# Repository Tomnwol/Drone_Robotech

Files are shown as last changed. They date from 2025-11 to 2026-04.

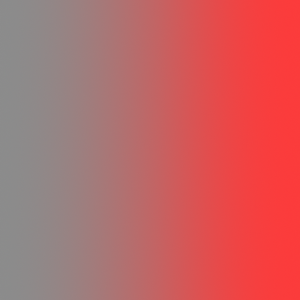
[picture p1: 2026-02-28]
Emitter/QT_Controller/half_texture.png

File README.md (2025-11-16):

Bienvenue dans le git du drone de **Robotech** 2025/2026.
Notre projet est de créer un drone 5" basé sur une ESP32.

# -- Démarche globale --

L'idée principale est d'utiliser un IMU 9 axes (accéléromètre, gyroscope, magnétomètre) pour obtenir une estimation d'attitude et ainsi pouvoir obtenir une commande angulaire qui sera par la suite exécutée par les moteurs.

# -- COMPOSANTS --

- Microprocesseur : *ESP32 DevKit*
- Accéléromètre/Gyroscope : *MPU-9265*
- Magnétomètre : *GY-271* (optionnel)
- Moteurs : *XING-E Pro 2207 1800KV 2-6S - Iflight*
- ESC : Hobbywing - *XRotor Micro 65A G2 4in1 AM32*
- Batterie : *LiPo GNB 6S 2200mAh 120C - XT60 - Gaoneng*
- Antenne RF : *NRF24L01 + PA/LNA*
- Frame : créée sur Fusion et imprimée en 3D
- PCB : créé sur Kicad 9

# -- CODE --

Pour le code, après avoir eu des problèmes de librairie en ESP-IDF sur **PlatformIo** pour le DSHOT, nous avons finalement migré vers **Arduino IDE** pour avoir une version plus récente de la librairie DSHOTRMT.

# -- SIMULATION --

Un fichier de simulation est disponible dans le répertoire /Simulation et permet de visualiser si le calcul d'attitude est cohérent et de visualiser 4 réponses moteurs, permettant ainsi de modifier les PID en conséquence.

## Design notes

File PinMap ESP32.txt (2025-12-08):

Association des GPIO de notre ESP-32 DevKit (30 pins)
GPIO 13 -> Moteur 1
GPIO 12 -> ReadyToFlyLED
GPIO 14 -> SDA1
GPIO 27 -> Moteur 2
GPIO 26 -> Moteur 3               
GPIO 25 -> SCL1
GPIO 33 -> Moteur 4
GPIO 32 
GPIO 35
GPIO 34 -> GPLED
GPIO 39
GPIO 36 -> Cut moteur si batterie trop faible
GPIO 15
GPIO 02
GPIO 04 -> CE_NRF
GPIO 16
GPIO 17
GPIO 05 -> CSN_NRF
GPIO 18 -> SCK
GPIO 19 -> MISO_NRF
GPIO 21 -> SDA0
GPIO 03
GPIO 01
GPIO 22 -> SCL0
GPIO 23 -> MOSI_NRF

Pinout moteur fonctionnel
13, 26, 27, 33

Défectueux : 14, 32

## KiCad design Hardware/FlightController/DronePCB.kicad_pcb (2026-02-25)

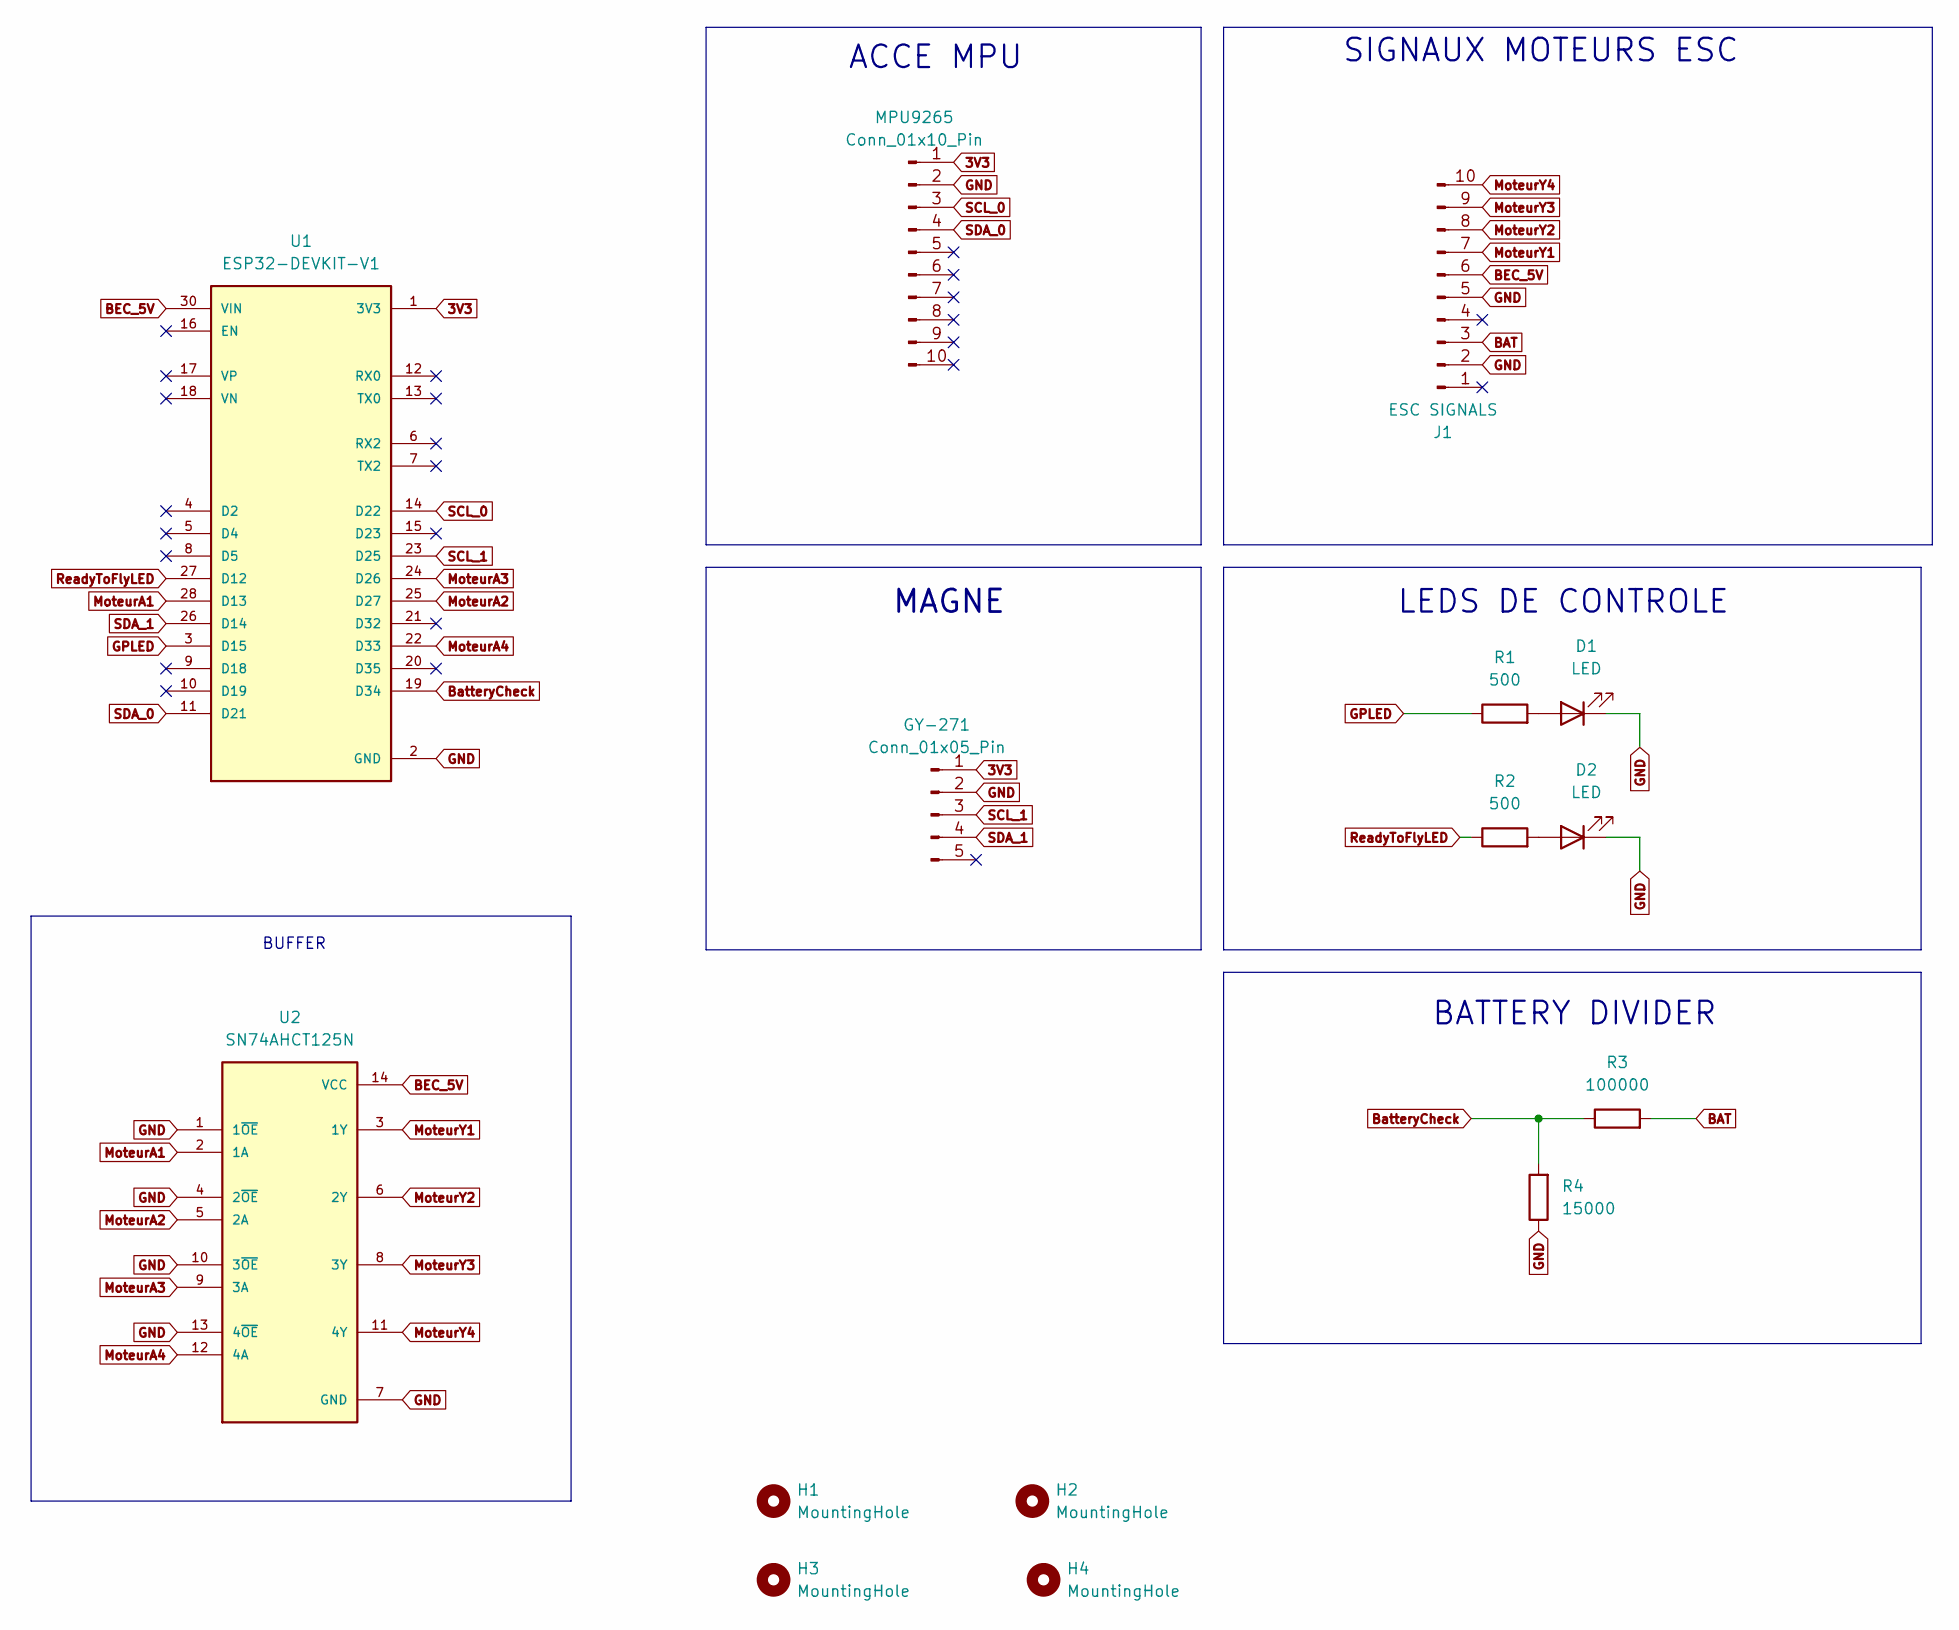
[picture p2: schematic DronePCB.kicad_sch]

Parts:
D1, D2: LED; LED_0603_1608Metric_Pad1.05x0.95mm_HandSolder
GY-271: Conn_01x05_Pin; PinHeader_1x05_P2.54mm_Vertical
H1, H2, H3, H4: MountingHole; MountingHole_3.2mm_M3_Pad
J1: ESC SIGNALS; JST_SHL_SM10B-SHLS-TF_1x10-1MP_P1.00mm_Horizontal
MPU9265: Conn_01x10_Pin; PinHeader_1x10_P2.54mm_Vertical
R1, R2: 500; R_0603_1608Metric_Pad0.98x0.95mm_HandSolder
R3: 100000; R_0603_1608Metric_Pad0.98x0.95mm_HandSolder
R4: 15000; R_0603_1608Metric_Pad0.98x0.95mm_HandSolder
U1: ESP32-DEVKIT-V1; MODULE_ESP32_DEVKIT_V1; PARTREV N/A
U2: SN74AHCT125N; DIP794W45P254L1930H508Q14; PARTREV Q

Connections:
3V3: GY-271.1, MPU9265.1, U1.1 (3V3)
BAT: J1.3, R3.2
BEC_5V: J1.6, U1.30 (VIN), U2.14 (VCC)
BatteryCheck: R3.1, R4.2, U1.19 (D34)
GND: D1.1 (K), D2.1 (K), GY-271.2, J1.2, J1.5, MPU9265.2, R4.1, U1.2 (GND), U1.29 (GND), U2.1 (1~OE), U2.4 (2~OE), U2.7 (GND), U2.10 (3~OE), U2.13 (4~OE)
GPLED: R1.1, U1.3 (D15)
MoteurA1: U1.28 (D13), U2.2 (1A)
MoteurA2: U1.25 (D27), U2.5 (2A)
MoteurA3: U1.24 (D26), U2.9 (3A)
MoteurA4: U1.22 (D33), U2.12 (4A)
MoteurY1: J1.7, U2.3 (1Y)
MoteurY2: J1.8, U2.6 (2Y)
MoteurY3: J1.9, U2.8 (3Y)
MoteurY4: J1.10, U2.11 (4Y)
unnamed: D1.2 (A), R1.2
unnamed: D2.2 (A), R2.2
ReadyToFlyLED: R2.1, U1.27 (D12)
SCL_0: MPU9265.3, U1.14 (D22)
SCL_1: GY-271.3, U1.23 (D25)
SDA_0: MPU9265.4, U1.11 (D21)
SDA_1: GY-271.4, U1.26 (D14)

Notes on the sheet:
ACCE MPU
MAGNE
BUFFER
BATTERY DIVIDER
LEDS DE CONTROLE
SIGNAUX MOTEURS ESC

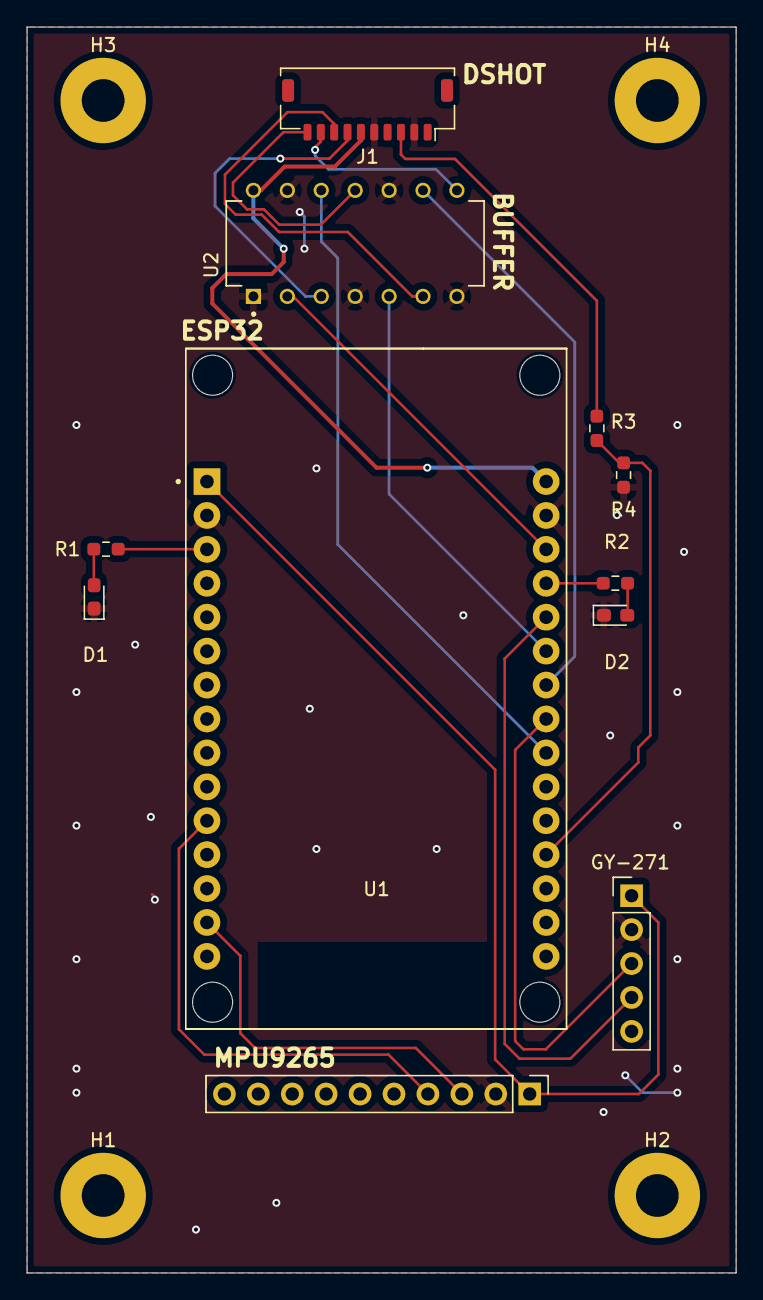
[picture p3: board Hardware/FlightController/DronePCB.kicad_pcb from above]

Board: 2 copper layers, 53.1 x 93.3 mm, 15 parts (0 on the bottom side), 21 nets.

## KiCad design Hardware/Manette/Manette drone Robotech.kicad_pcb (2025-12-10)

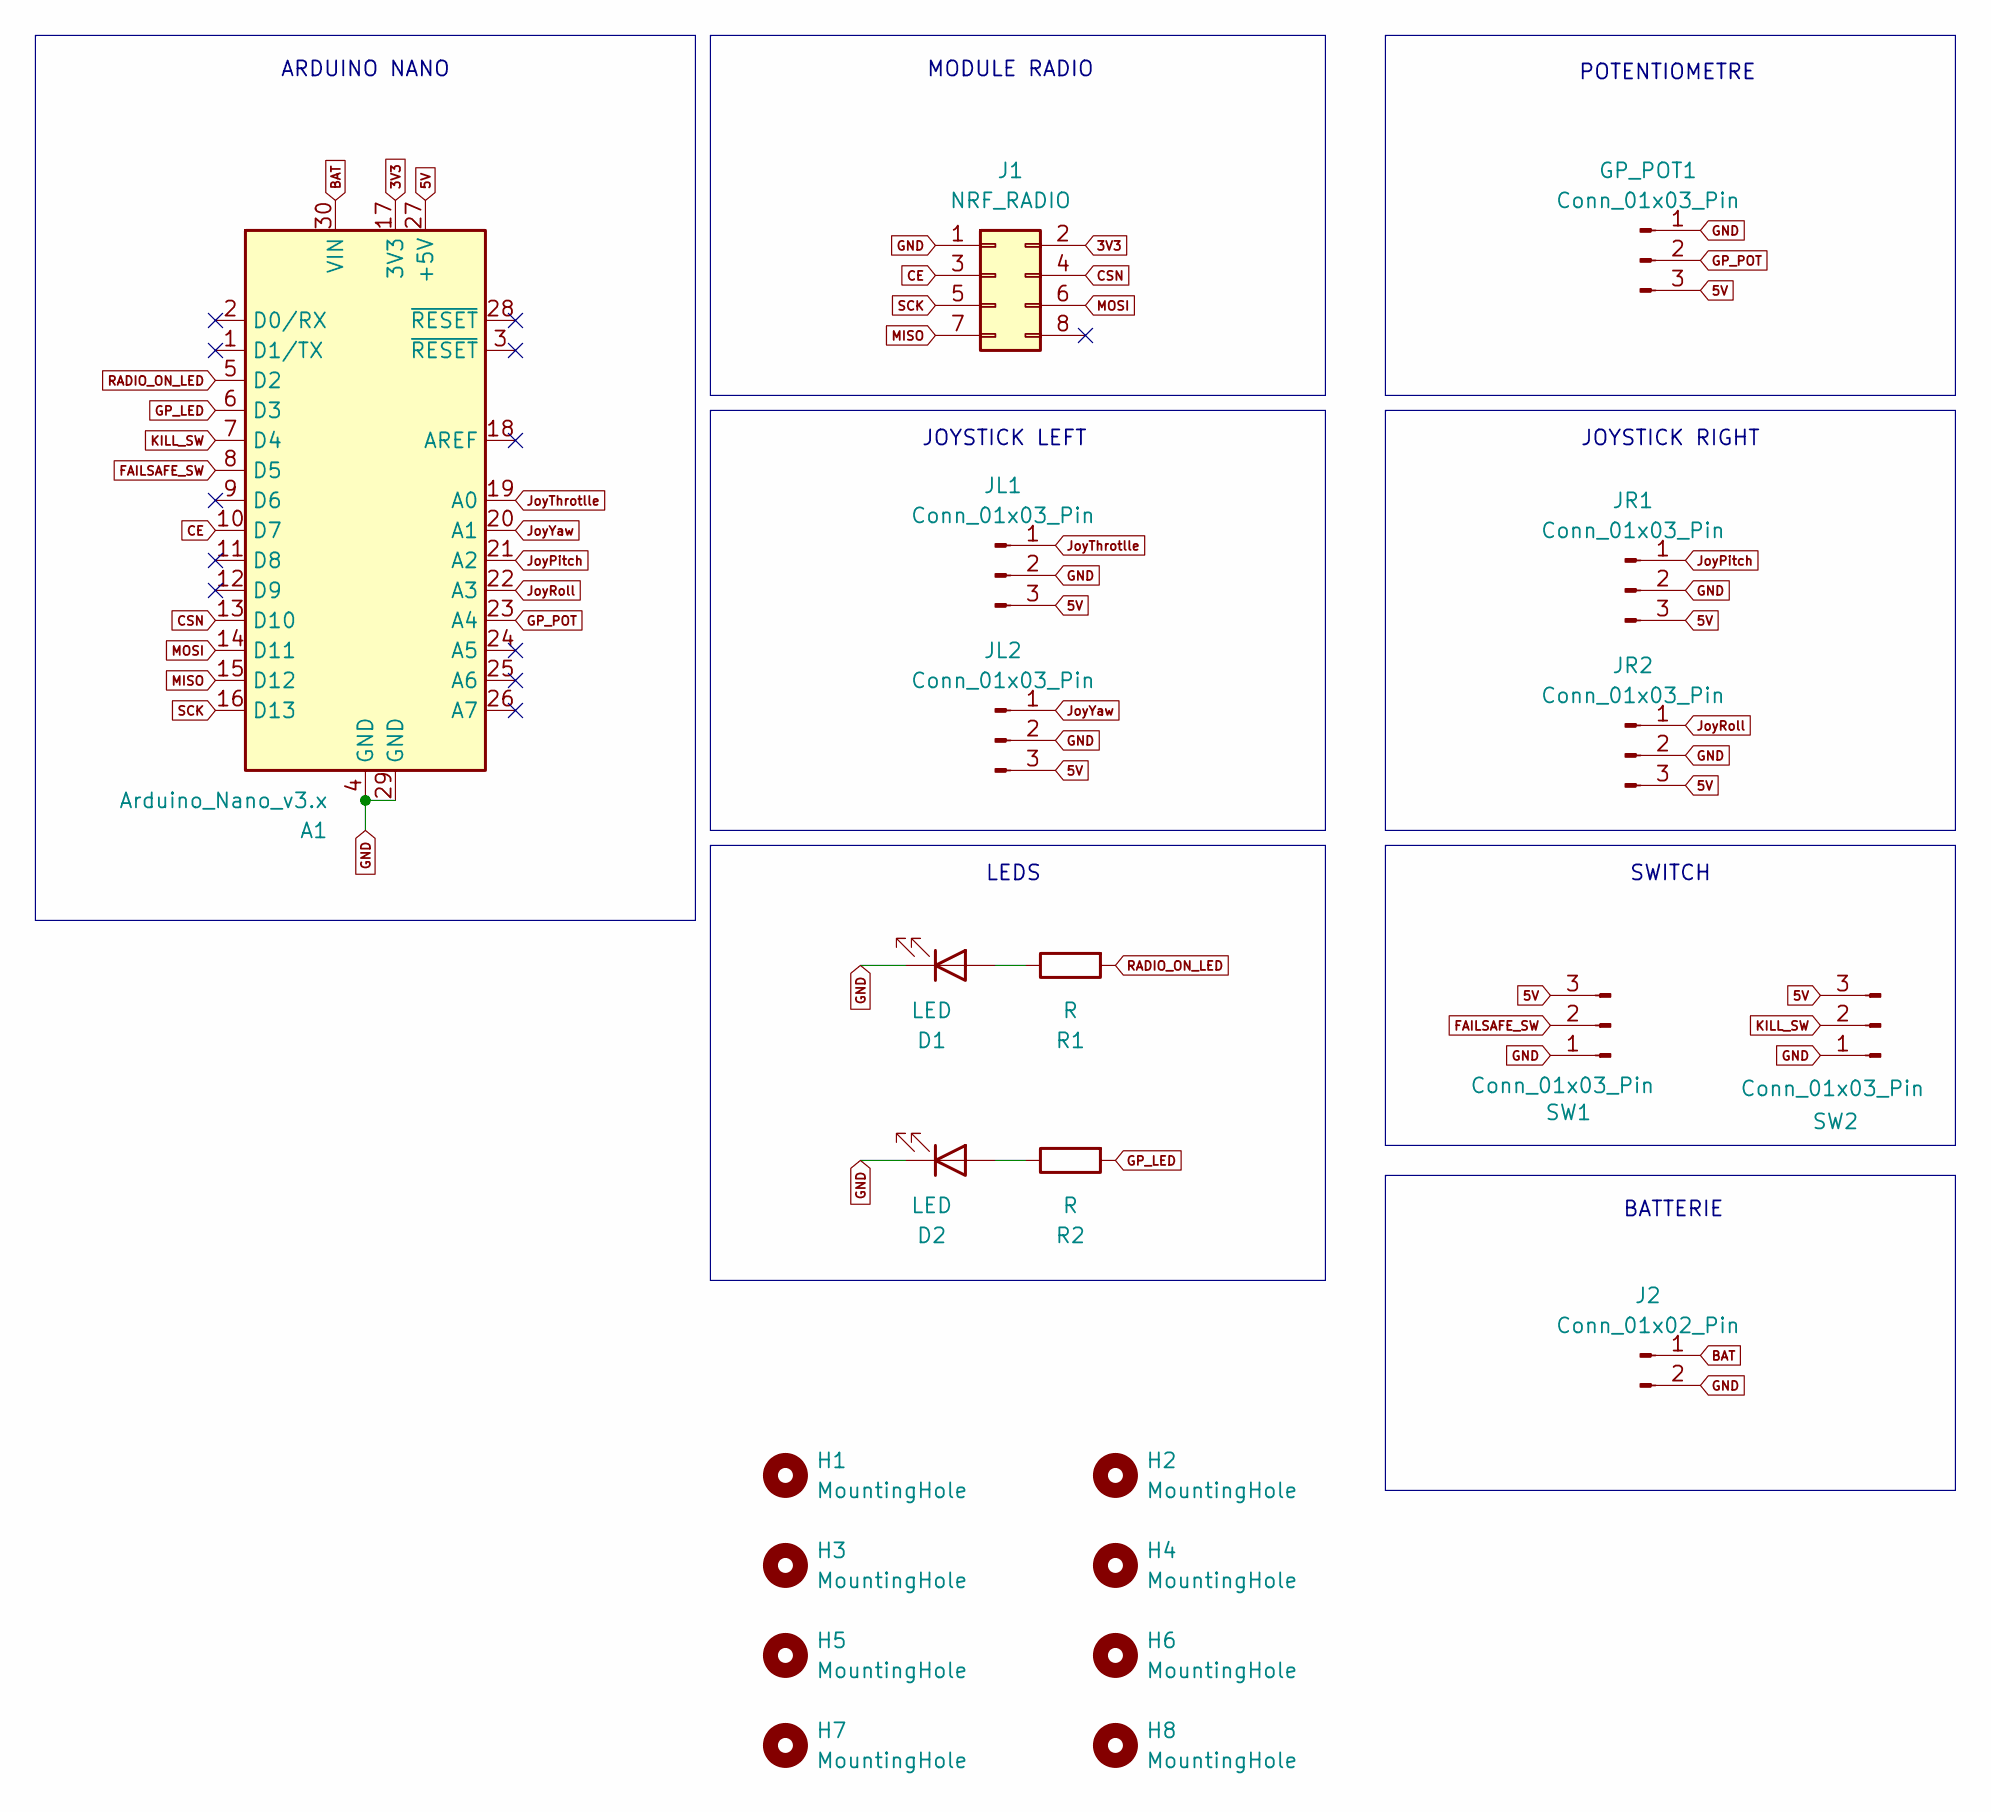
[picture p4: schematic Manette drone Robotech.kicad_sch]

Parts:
A1: Arduino_Nano_v3.x; Arduino_Nano
D1, D2: LED; LED_0603_1608Metric_Pad1.05x0.95mm_HandSolder
GP_POT1: Conn_01x03_Pin; PinHeader_1x03_P2.54mm_Vertical
H1, H2, H3, H4, H5, H6, H7, H8: MountingHole; MountingHole_3.2mm_M3_Pad
J1: NRF_RADIO; PinHeader_2x04_P2.54mm_Vertical
J2: Conn_01x02_Pin; PinHeader_1x02_P2.54mm_Vertical
JL1, JL2: Conn_01x03_Pin; PinHeader_1x03_P2.54mm_Vertical
JR1, JR2: Conn_01x03_Pin; PinHeader_1x03_P2.54mm_Vertical
R1, R2: R; R_0603_1608Metric_Pad0.98x0.95mm_HandSolder
SW1, SW2: Conn_01x03_Pin; PinHeader_1x03_P2.54mm_Vertical

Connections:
3V3: A1.17 (3V3), J1.2
5V: A1.27 (+5V), GP_POT1.3, JL1.3, JL2.3, JR1.3, JR2.3, SW1.3, SW2.3
BAT: A1.30 (VIN), J2.1
CE: A1.10 (D7), J1.3
CSN: A1.13 (D10), J1.4
FAILSAFE_SW: A1.8 (D5), SW1.2
GND: A1.4 (GND), A1.29 (GND), D1.1 (K), D2.1 (K), GP_POT1.1, J1.1, J2.2, JL1.2, JL2.2, JR1.2, JR2.2, SW1.1, SW2.1
GP_LED: A1.6 (D3), R2.2
GP_POT: A1.23 (A4), GP_POT1.2
JoyPitch: A1.21 (A2), JR1.1
JoyRoll: A1.22 (A3), JR2.1
JoyThrotlle: A1.19 (A0), JL1.1
JoyYaw: A1.20 (A1), JL2.1
KILL_SW: A1.7 (D4), SW2.2
MISO: A1.15 (D12), J1.7
MOSI: A1.14 (D11), J1.6
unnamed: D1.2 (A), R1.1
unnamed: D2.2 (A), R2.1
RADIO_ON_LED: A1.5 (D2), R1.2
SCK: A1.16 (D13), J1.5

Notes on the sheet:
JOYSTICK LEFT
JOYSTICK RIGHT
MODULE RADIO
SWITCH
LEDS
BATTERIE
POTENTIOMETRE
ARDUINO NANO

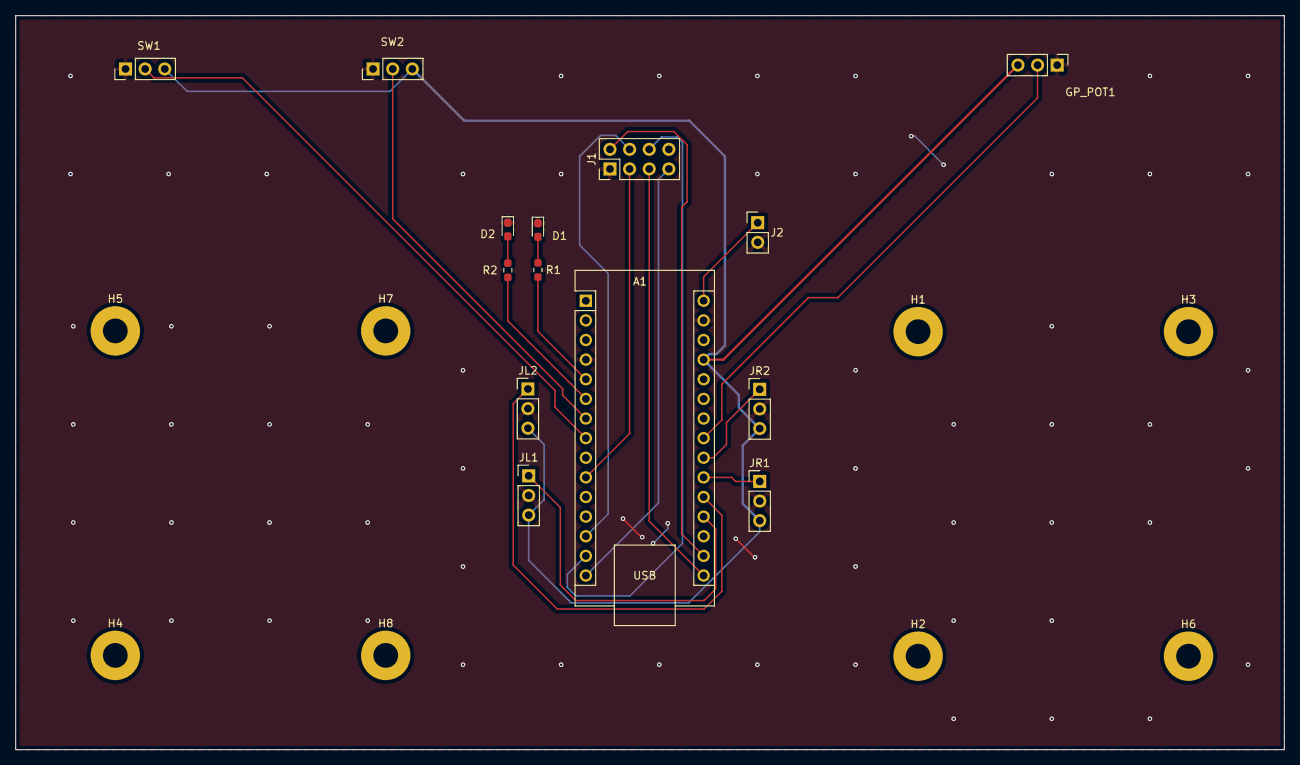
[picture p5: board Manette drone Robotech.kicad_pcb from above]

Board: 2 copper layers, 164.2 x 95.0 mm, 22 parts (0 on the bottom side), 20 nets.

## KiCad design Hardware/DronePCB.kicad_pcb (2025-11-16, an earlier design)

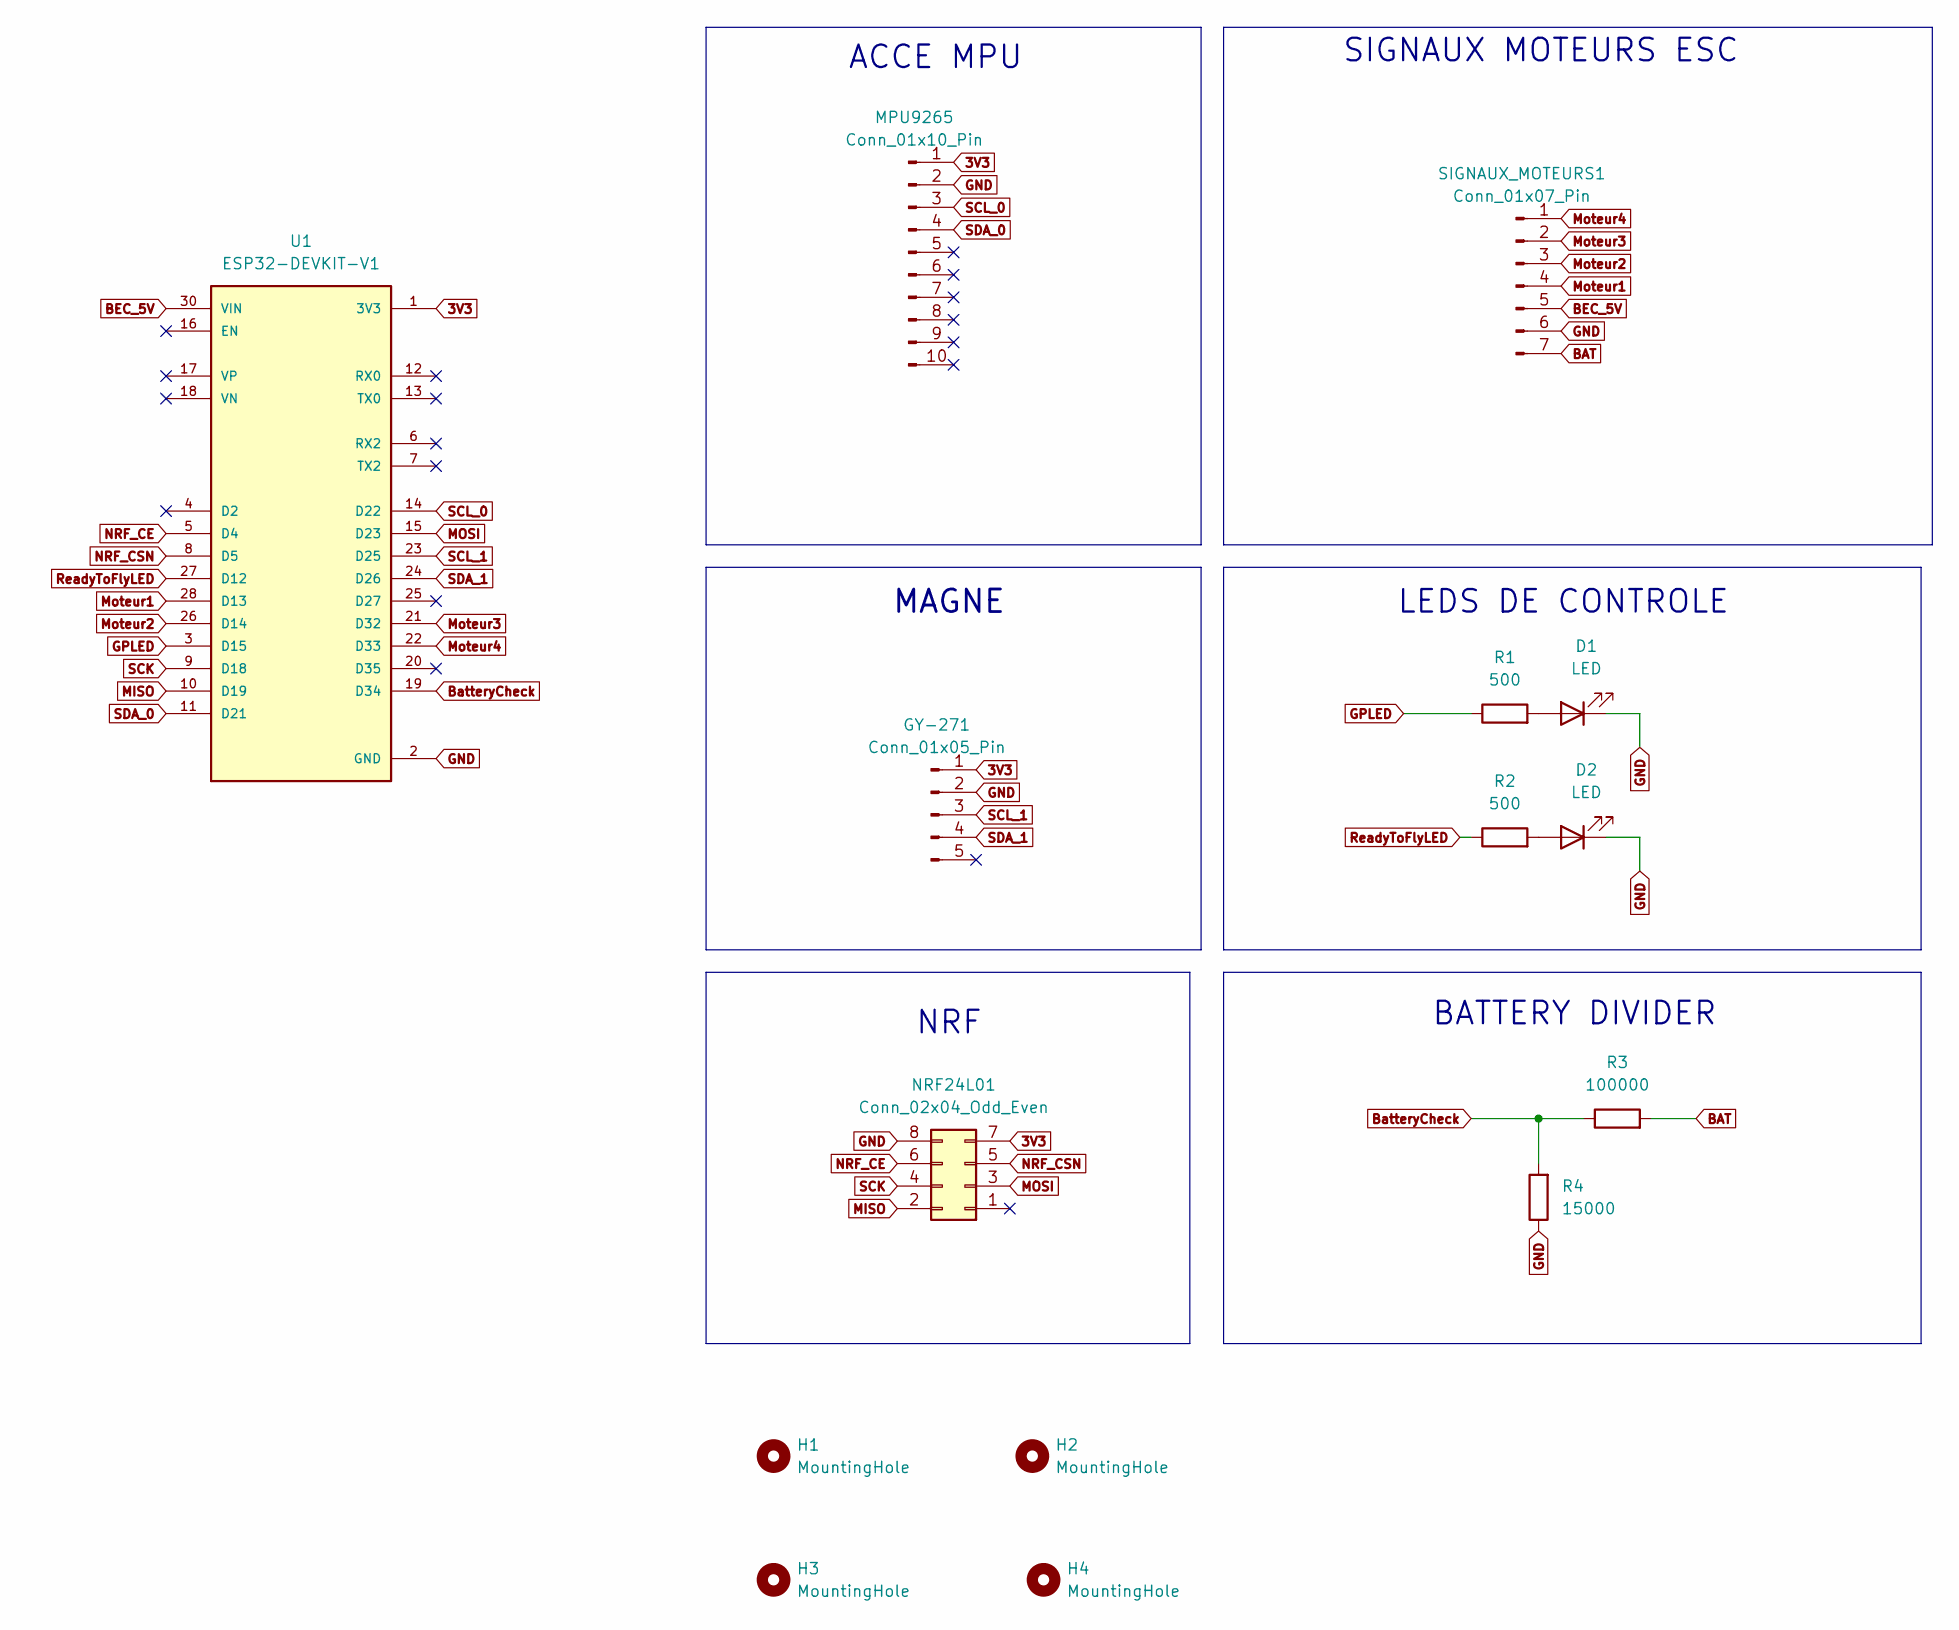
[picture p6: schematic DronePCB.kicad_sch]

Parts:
D1, D2: LED; LED_0603_1608Metric_Pad1.05x0.95mm_HandSolder
GY-271: Conn_01x05_Pin; PinHeader_1x05_P2.54mm_Vertical
H1, H2, H3, H4: MountingHole; MountingHole_3.2mm_M3_Pad
MPU9265: Conn_01x10_Pin; PinHeader_1x10_P2.54mm_Vertical
NRF24L01: Conn_02x04_Odd_Even; PinHeader_2x04_P2.00mm_Vertical
R1, R2: 500; R_0603_1608Metric_Pad0.98x0.95mm_HandSolder
R3: 100000; R_0603_1608Metric_Pad0.98x0.95mm_HandSolder
R4: 15000; R_0603_1608Metric_Pad0.98x0.95mm_HandSolder
SIGNAUX_MOTEURS1: Conn_01x07_Pin; PinHeader_1x07_P2.54mm_Vertical
U1: ESP32-DEVKIT-V1; MODULE_ESP32_DEVKIT_V1; PARTREV N/A

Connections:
3V3: GY-271.1, MPU9265.1, NRF24L01.7, U1.1 (3V3)
BAT: R3.2, SIGNAUX_MOTEURS1.7; also elsewhere on the board
BEC_5V: SIGNAUX_MOTEURS1.5, U1.30 (VIN); also elsewhere on the board
BatteryCheck: R3.1, R4.2, U1.19 (D34)
GND: D1.1 (K), D2.1 (K), GY-271.2, MPU9265.2, NRF24L01.8, R4.1, SIGNAUX_MOTEURS1.6, U1.2 (GND), U1.29 (GND); also elsewhere on the board
GPLED: R1.1, U1.3 (D15)
MISO: NRF24L01.2, U1.10 (D19)
MOSI: NRF24L01.3, U1.15 (D23)
Moteur1: SIGNAUX_MOTEURS1.4, U1.28 (D13); also elsewhere on the board
Moteur2: SIGNAUX_MOTEURS1.3, U1.26 (D14); also elsewhere on the board
Moteur3: SIGNAUX_MOTEURS1.2, U1.21 (D32); also elsewhere on the board
Moteur4: SIGNAUX_MOTEURS1.1, U1.22 (D33); also elsewhere on the board
NRF_CE: NRF24L01.6, U1.5 (D4)
NRF_CSN: NRF24L01.5, U1.8 (D5)
unnamed: D1.2 (A), R1.2
unnamed: D2.2 (A), R2.2
ReadyToFlyLED: R2.1, U1.27 (D12)
SCK: NRF24L01.4, U1.9 (D18)
SCL_0: MPU9265.3, U1.14 (D22)
SCL_1: GY-271.3, U1.23 (D25)
SDA_0: MPU9265.4, U1.11 (D21)
SDA_1: GY-271.4, U1.24 (D26)

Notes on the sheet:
ACCE MPU
MAGNE
BATTERY DIVIDER
LEDS DE CONTROLE
SIGNAUX MOTEURS ESC
NRF

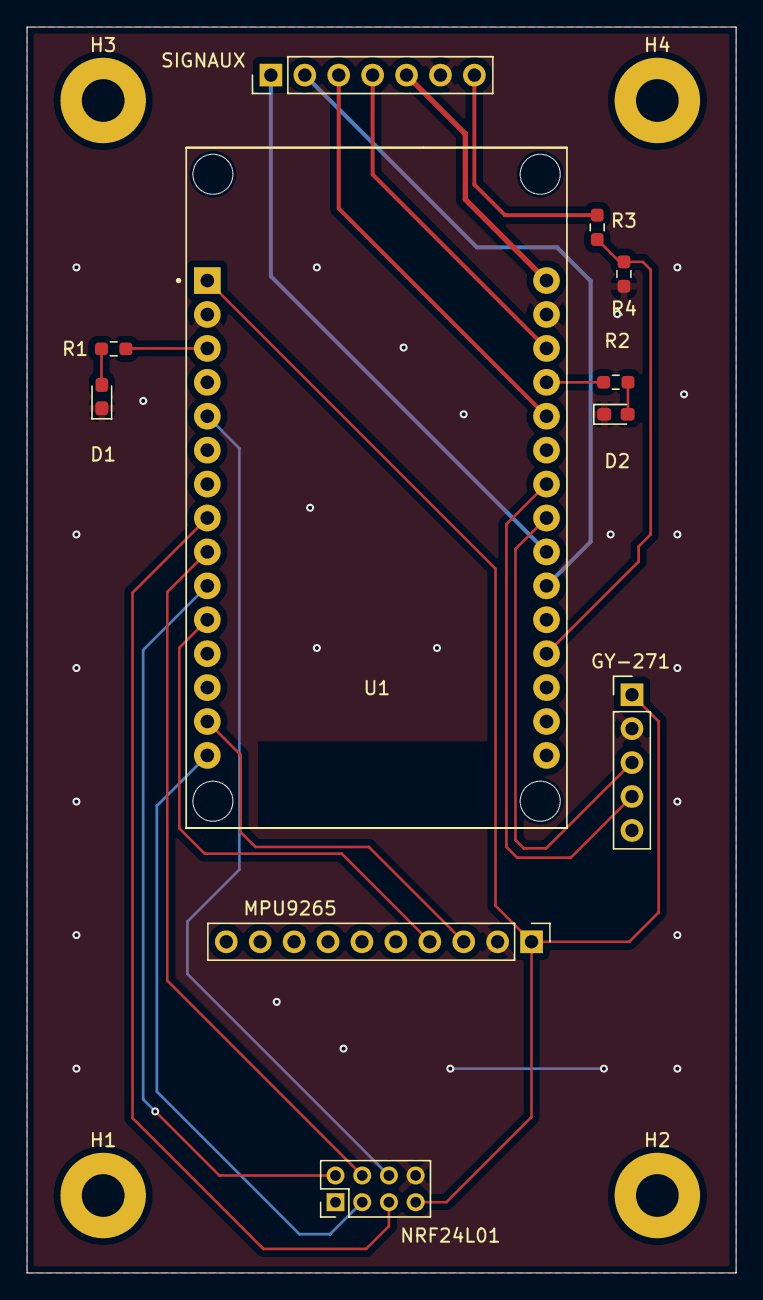
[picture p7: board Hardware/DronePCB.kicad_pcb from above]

Board: 2 copper layers, 53.1 x 93.3 mm, 15 parts (0 on the bottom side), 22 nets.

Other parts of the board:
SIGNAUX: Conn_01x07_Pin; PinHeader_1x07_P2.54mm_Vertical

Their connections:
BAT: SIGNAUX.7; also elsewhere on the board
BEC_5V: SIGNAUX.5; also elsewhere on the board
GND: SIGNAUX.6; also elsewhere on the board
Moteur1: SIGNAUX.4; also elsewhere on the board
Moteur2: SIGNAUX.3; also elsewhere on the board
Moteur3: SIGNAUX.2; also elsewhere on the board
Moteur4: SIGNAUX.1; also elsewhere on the board

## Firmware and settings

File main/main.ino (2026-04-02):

//#include "Arduino.h"
#include <stdio.h>
#include <Arduino.h>
#include <DShotRMT.h>
#include "i2c_basics.hpp"
#include "MadgwickAHRS.hpp"
#include "esp_timer.h"
#include "esp_log.h"
#include "imu.hpp"
#include "types.hpp"
#include "utils.hpp"
#include "UDP_reception.hpp"
//#include "NRF_receiver.hpp"
#include "pid.hpp"

static constexpr gpio_num_t MOTOR_FL_PIN = GPIO_NUM_13; //MOT1
static constexpr gpio_num_t MOTOR_FR_PIN = GPIO_NUM_26;//GPIO_NUM_32; //MOT3
static constexpr gpio_num_t MOTOR_BL_PIN = GPIO_NUM_27;//GPIO_NUM_14; //MOT2
static constexpr gpio_num_t MOTOR_BR_PIN = GPIO_NUM_33; //MOT4
static constexpr gpio_num_t ARM_LED = GPIO_NUM_12; //HIGH state indicates that the drone is ready to fly
static constexpr gpio_num_t GP_LED = GPIO_NUM_15;
static constexpr dshot_mode_t MODE = DSHOT600;
DShotRMT motorFL(MOTOR_FL_PIN, MODE, false);
DShotRMT motorFR(MOTOR_FR_PIN, MODE, false);
DShotRMT motorBL(MOTOR_BL_PIN, MODE, false);
DShotRMT motorBR(MOTOR_BR_PIN, MODE, false);

#define TIME_BEFORE_MOTOR_ACTIVATION 20000000
#define BASE_THRUST_MIN 100
#define BASE_THRUST_MAX 1900
#define BASE_THRUST_MAX_FAILSAFE 700
#define BASE_THRUST_FAILSAFE_AUTO 400

#define MOTOR_MAX_VALUE 2047
#define MOTOR_FAILSAFE_MAX_VALUE 800

#define MOTOR_SLEW_RATE 2000 //DSHOT units/s 
#define OFFSET_MOTOR_MAX 100
int failsafe_mode = 0; /* 0->OK  1->Activation FS par radio  2->Communication perdue */
bool killswitch_enable = false; /* Si le mode KS est activé, il ne pourra plus être désactivé avant redémarrage */ 
bool is_arm_mode_enable = false;
#define SIZE_TAB  2
float tab_acce[3][SIZE_TAB] = {{0},{0},{0}}; //stocke les dernières valeurs d'accélération
float tab_gyro[3][SIZE_TAB] = {{0},{0},{0}}; //stocke les dernières valeurs du gyro
float tab_magne[3][SIZE_TAB] = {{0},{0},{0}}; //stocke les dernières valeurs du mangétomètre

bool I2C_init_error = false;
void fill_queues(Vector3f accel_vect, Vector3f gyro_vect, Vector3f magne_vect){
    fill_queue(tab_acce[0], SIZE_TAB, accel_vect.x);
    fill_queue(tab_acce[1], SIZE_TAB, accel_vect.y);
    fill_queue(tab_acce[2], SIZE_TAB, accel_vect.z);
    fill_queue(tab_gyro[0], SIZE_TAB, gyro_vect.x);
    fill_queue(tab_gyro[1], SIZE_TAB, gyro_vect.y);
    fill_queue(tab_gyro[2], SIZE_TAB, gyro_vect.z);
    fill_queue(tab_magne[0], SIZE_TAB, magne_vect.x);
    fill_queue(tab_magne[1], SIZE_TAB, magne_vect.y);
    fill_queue(tab_magne[2], SIZE_TAB, magne_vect.z);
}

void passes_bas(float dt){
    float f_c_acce = 60.;
    float f_c_gyro = 130.;
    float f_c_magne = 50.;
    tab_acce[0][0] = passe_bas(tab_acce[0][0], tab_acce[0][1], dt, f_c_acce);
    tab_acce[1][0] = passe_bas(tab_acce[1][0], tab_acce[1][1], dt, f_c_acce);
    tab_acce[2][0] = passe_bas(tab_acce[2][0], tab_acce[2][1], dt, f_c_acce);

    tab_gyro[0][0] = passe_bas(tab_gyro[0][0], tab_gyro[0][1], dt, f_c_gyro);
    tab_gyro[1][0] = passe_bas(tab_gyro[1][0], tab_gyro[1][1], dt, f_c_gyro);
    tab_gyro[2][0] = passe_bas(tab_gyro[2][0], tab_gyro[2][1], dt, f_c_gyro);

    tab_magne[0][0] = passe_bas(tab_magne[0][0], tab_magne[0][1], dt, f_c_magne);
    tab_magne[1][0] = passe_bas(tab_magne[1][0], tab_magne[1][1], dt, f_c_magne);
    tab_magne[2][0] = passe_bas(tab_magne[2][0], tab_magne[2][1], dt, f_c_magne);
}


float get_base_thrust_max(){
    if (failsafe_mode){
      return BASE_THRUST_MAX_FAILSAFE;
    }else{
      return BASE_THRUST_MAX;
    }
}

float get_motor_max_value(){
    if (failsafe_mode){
      return MOTOR_FAILSAFE_MAX_VALUE;
    }else{
      return MOTOR_MAX_VALUE;
    }
}

float prev_mFL = 48.0f;
float prev_mFR = 48.0f;
float prev_mBR = 48.0f;
float prev_mBL = 48.0f;
void motors_zeroes(){
  prev_mFL = 48.0f; prev_mFR = 48.0f; prev_mBR = 48.0f; prev_mBL = 48.0f;
  motorFL.sendThrottle(48);
  motorFR.sendThrottle(48);
  motorBL.sendThrottle(48);
  motorBR.sendThrottle(48);
}

void motor_initial_sequence(){
  unsigned long start = millis();
  while (millis() - start < 1000) {
    motorFL.sendThrottle(0);
    motorFR.sendThrottle(0);
    motorBL.sendThrottle(0);
    motorBR.sendThrottle(0);
    delay(2);
  }
  delay(500);
  for (uint16_t t = 48; t <= 200; ++t) {
    motorFL.sendThrottle(t);
    motorFR.sendThrottle(t);
    motorBL.sendThrottle(t);
    motorBR.sendThrottle(t);
    delay(5); // ramp lente
  }
  // Retour à zéro
  for (uint16_t t = 200; t >= 48; --t) {
    motorFL.sendThrottle(t);
    motorFR.sendThrottle(t);
    motorBL.sendThrottle(t);
    motorBR.sendThrottle(t);
    delay(5);
  }
}

bool arm_mode_enable(){
  static int arming_counter = 0;
  if (joyThrottle == 48 && udp_delta_time < 100){
    arming_counter++;
    if (arming_counter >= 10){
      return true;
    }
  }else{
    arming_counter = 0;
  }
  return false;
}

bool is_kill_mode_enable(){ /* Non réversible mode -> désactivation des moteurs */
  if (killswitch_enable == false){
    if (is_arm_mode_enable && (udp_delta_time > 1000)){ //1500 ! Pour les TESTS ON MET + MAIS ATTENTION A BIEN REMETTRE 1500 PLUS TARD
      killswitch_enable = true;
      Serial.println("KS -> Communication failed");
      return true;
    }
    if (SWKillSwitch){ // Si la radio a reçu un signal KillSwitch
      killswitch_enable = true;
      Serial.println("KS -> KS flag received");
      return true;
    }else{
      return false;
    }
    return false;
  }else{
    return true;
  }
}

void failsafe_mode_activation(){  /* 0->OK  1->Activation par radio  2->Communication perdue */
  if (is_arm_mode_enable && udp_delta_time > 500){ // La radio ne répond plus depuis 0.5s => failsafe mode => limiation moteur
    failsafe_mode = 2;
    return;
  }
  failsafe_mode = SWFailSafe;
}

void error_loop_blink(){
  while(1){
    delay(200);
    Serial.println("KS_Activated");
    digitalWrite(GP_LED, HIGH);
    delay(200);
    digitalWrite(GP_LED, LOW);
  }
}

void fc_task() { 
    static int debug_counter_inner = 0;
    static unsigned long lastTime_outter = 0;
    static unsigned long lastTime_inner = 0;
    static int debug_counter = 0;
    static int debug_counter2 = 0;
    debug_counter_inner++;
    debug_counter2++;

    static int magne_compteur = 0;
    static Quaternion q_drone = {1, 0, 0, 0};
    static Vector3f omega_set = {0};
    static Vector3f magne_vect = {0, 0, 0};
    static Euler att_telemetry = {0,0,0};
    static float yawCommand = 0;
    static uint16_t MOT_FL_telemetry = 48;
    static uint16_t MOT_FR_telemetry = 48;
    static uint16_t MOT_BR_telemetry = 48;
    static uint16_t MOT_BL_telemetry = 48;

    handleSendTelemetry(att_telemetry, MOT_FL_telemetry, MOT_FR_telemetry, MOT_BR_telemetry, MOT_BL_telemetry);

    unsigned long now = micros(); // microsecondes
    float dt_inner = (now - lastTime_inner) / 1000000.0f; // s [Si bug -> Vérifier que dt_inner ne vaut jamais 0]
    lastTime_inner = now;

    // Lecture capteurs
    Vector3f accel_vect = read_accel();
    Vector3f gyro_vect  = read_gyro();
    magne_compteur++;
    fill_queues(accel_vect, gyro_vect, magne_vect);
    passes_bas(dt_inner);

    float dt_outer = (now - lastTime_outter) / 1000000.0f; // s
    /* OUTER LOOP */
    if (dt_outer > 0.004f) { // ~250 Hz
        lastTime_outter = now;
        float sampleFreqLocal = 1.0f / dt_outer;
        readUDPData();

        MadgwickAHRSupdate(
            sampleFreqLocal,
            tab_gyro[0][0], tab_gyro[1][0], tab_gyro[2][0],
            tab_acce[0][0], tab_acce[1][0], tab_acce[2][0],
            //tab_magne[0][0], tab_magne[1][0], tab_magne[2][0]
            0, 0, 0
        );
        q_drone.w = q0; q_drone.x = q1; q_drone.y = q2; q_drone.z = q3;
      
        Euler att = quat_to_euler(q_drone); // Obtiens l'attitude en Euler
        att_telemetry = att;
        const float SECURITY_ANGLE_RAD = 45.0f * M_PI / 180.0f;
        if (now > TIME_BEFORE_MOTOR_ACTIVATION * 0.8 && (fabs(att.roll) > SECURITY_ANGLE_RAD || fabs(att.pitch) > SECURITY_ANGLE_RAD)){
          killswitch_enable = true;
          Serial.println("KS -> Security angle");
        }

        Euler att_desired = get_att_desired();
        yawCommand = att_desired.yaw;
        omega_set = get_angular_rate_command(att, att_desired);
    }

    Vector3f torque = get_torque(omega_set, (Vector3f){tab_gyro[0][0], tab_gyro[1][0], tab_gyro[2][0]}, (Vector3f){tab_gyro[0][1], tab_gyro[1][1], tab_gyro[2][1]}, dt_inner);
    
    if (killswitch_enable){
      error_loop_blink();
    }
    bool motor_zero = false;
    if(now < TIME_BEFORE_MOTOR_ACTIVATION * 0.9 ){
      motor_zero = true;
    }
    digitalWrite(GP_LED, HIGH);
    // Vérification de l'armement du drone. Une fois que le drone est armé, ce n'est plus vérfié
    if (debug_counter2 >= 100) {
      debug_counter2 = 0;
      Serial.printf("DEBUG2:%d, %d\n", joyThrottle, udp_delta_time);
    }
    if( !is_arm_mode_enable ){ 
      is_arm_mode_enable = arm_mode_enable();

      if (is_arm_mode_enable){ //La LED prévient que le drone a été armé
        digitalWrite(ARM_LED, HIGH);
        //Ce serait mieux d'armer les moteurs ici, cependant, => Problématique en communication unidirectionnelle si un moteur failli ( et si on laisse une séquence de démarrage tout ça, après on a le problème de l'algo de Madwick qui se perd)
      }
      motor_zero = true;
    }
    
    failsafe_mode_activation();
    float base_thrust_max = get_base_thrust_max();
    float base_thrust;
    if (failsafe_mode != 2){
      base_thrust = (float)joyThrottle;
    }else{ // FS 2 -> Communication perdue
      base_thrust = BASE_THRUST_FAILSAFE_AUTO;
    }

    base_thrust = float_clamp(base_thrust, BASE_THRUST_MIN, base_thrust_max);


    if(now < TIME_BEFORE_MOTOR_ACTIVATION || is_kill_mode_enable()){ // ATTENTION A BIEN REGLER LA VALEUR DE DELTA RADIO LORS DUN VRAI VOL
      motor_zero = true;
    }
    //float commandYaw = joyYaw;
    float motor_max_value = get_motor_max_value();
    // Remarque: sur ce montage, l'IMU est orientée de 90°
    // => gyro.x = roulis (roll), gyro.y = tangage (pitch)
    //On peut viser : torque.x, torque.y ∈ [-100, +100] & base_thrust ∈ [100 à 1900]
    float mFL_target = float_clamp((base_thrust + torque.y - torque.x + yawCommand + uint8_clamp(offsetMotorFL, 0, OFFSET_MOTOR_MAX) ), 48.0, motor_max_value);
    float mFR_target = float_clamp((base_thrust + torque.y + torque.x - yawCommand + uint8_clamp(offsetMotorFR, 0, OFFSET_MOTOR_MAX) ), 48.0, motor_max_value);
    float mBR_target = float_clamp((base_thrust - torque.y + torque.x + yawCommand + uint8_clamp(offsetMotorBR, 0, OFFSET_MOTOR_MAX) ), 48.0, motor_max_value);
    float mBL_target = float_clamp((base_thrust - torque.y - torque.x - yawCommand + uint8_clamp(offsetMotorBL, 0, OFFSET_MOTOR_MAX) ), 48.0, motor_max_value);

    // Appliquer slew limiter par moteur
    prev_mFL = slew_limit(mFL_target, prev_mFL, MOTOR_SLEW_RATE, dt_inner);
    prev_mFR = slew_limit(mFR_target, prev_mFR, MOTOR_SLEW_RATE, dt_inner);
    prev_mBR = slew_limit(mBR_target, prev_mBR, MOTOR_SLEW_RATE, dt_inner);
    prev_mBL = slew_limit(mBL_target, prev_mBL, MOTOR_SLEW_RATE, dt_inner);

    uint16_t MOT_FL = (uint16_t)float_clamp(prev_mFL, 48.0, motor_max_value);
    uint16_t MOT_FR = (uint16_t)float_clamp(prev_mFR, 48.0, motor_max_value);
    uint16_t MOT_BR = (uint16_t)float_clamp(prev_mBR, 48.0, motor_max_value);
    uint16_t MOT_BL = (uint16_t)float_clamp(prev_mBL, 48.0, motor_max_value);


    if(!motor_zero){
      MOT_FL_telemetry = MOT_FL;
      MOT_FR_telemetry = MOT_FR;
      MOT_BR_telemetry = MOT_BR;
      MOT_BL_telemetry = MOT_BL;
      motorFL.sendThrottle(MOT_FL);
      motorFR.sendThrottle(MOT_FR);
      motorBL.sendThrottle(MOT_BL);
      motorBR.sendThrottle(MOT_BR);
    }else{
      MOT_FL_telemetry = 48;
      MOT_FR_telemetry = 48;
      MOT_BR_telemetry = 48;
      MOT_BL_telemetry = 48;
      motors_zeroes();
    }

    debug_counter++;
    if (debug_counter >= 200) {
        debug_counter = 0;
        //Afficher également les commandes Moteur1,2,3,4////////////////////////////////////////////////////
        //Serial.printf("%f,%f,%f,%f,%d,%d,%d,%d\n", q_drone.w, q_drone.x, q_drone.y, q_drone.z,MOT_FL,MOT_FR,MOT_BL,MOT_BR );
        
    }
    delay(1);
}



void setup() {
    Serial.begin(115200);
    pinMode(ARM_LED, OUTPUT);
    pinMode(GP_LED, OUTPUT);
    pinMode(BATTERY_PIN, INPUT);
    digitalWrite(GP_LED, LOW);
    digitalWrite(ARM_LED, LOW);
    i2c_master_init(I2C_MASTER_0_PORT, I2C_MASTER_0_SDA_IO, I2C_MASTER_0_SCL_IO, I2C_MASTER_0_FREQ_HZ);
    setupUDP();
    calibrate_gyro();
    delay(100);
    motorFL.begin();
    motorFR.begin();
    motorBL.begin();
    motorBR.begin();
    motor_initial_sequence();
    delay(5); //JTAG Delay test
}


void loop() {
    fc_task();
}

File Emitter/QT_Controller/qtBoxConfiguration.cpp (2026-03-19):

#include <QVBoxLayout>
#include <QLabel>
#include <QSlider>
#include <QDoubleSpinBox>
#include <QPushButton>
#include <QTimer>
#include "UDP.hpp"
#include "controller.hpp"
#include "configuration.hpp"
#include "qtBoxConfiguration.hpp"
#include "qtStyles.hpp"

#define OFFSET_MOTOR_MAX 100

QDoubleSpinBox *kpSpin;
QDoubleSpinBox *kiSpin;
QDoubleSpinBox *kdSpin;

QGroupBox *configurationGroupBox = nullptr; // WARNING : ne pas intialiser en global sinon crash
QTimer *timerConfigurationUpdate = nullptr;
void initConfigurationBox(Config* config){
    configurationGroupBox = new QGroupBox("Configuration");
    configurationGroupBox->setStyleSheet(TITLE_LABEL_STYLE);

    /****3.Left offset****/
    QLabel *OM_FL_Label = new QLabel("");
    QSlider *OM_FL_Slider = new QSlider(Qt::Horizontal);
    //OM_FL_Slider->setInvertedAppearance(true);
    OM_FL_Slider->setRange(0, OFFSET_MOTOR_MAX);
    OM_FL_Slider->setValue(my_config.offsetMotorFL);
    payload.offsetMotorFL = 0;
    OM_FL_Label->setText("FrontLeft : " + QString::number(OM_FL_Slider->value()));

    QLabel *OM_BL_Label = new QLabel("");
    QSlider *OM_BL_Slider = new QSlider(Qt::Horizontal);
    OM_BL_Slider->setRange(0, OFFSET_MOTOR_MAX);
    OM_BL_Slider->setValue(my_config.offsetMotorBL);
    payload.offsetMotorBL = 0;
    OM_BL_Label->setText("BackLeft : " + QString::number(OM_BL_Slider->value()));

    /****3.Right offset****/
    QLabel *OM_FR_Label = new QLabel("");
    QSlider *OM_FR_Slider = new QSlider(Qt::Horizontal);
    OM_FR_Slider->setRange(0, OFFSET_MOTOR_MAX);
    OM_FR_Slider->setValue(my_config.offsetMotorFR);
    payload.offsetMotorFR = 0;
    OM_FR_Label->setText("FrontRight : " + QString::number(OM_FR_Slider->value()));

    QLabel *OM_BR_Label = new QLabel("");
    QSlider *OM_BR_Slider = new QSlider(Qt::Horizontal);
    OM_BR_Slider->setRange(0, OFFSET_MOTOR_MAX);
    OM_BR_Slider->setValue(my_config.offsetMotorBR);
    payload.offsetMotorBR = 0;
    OM_BR_Label->setText("BackRight : " + QString::number(OM_BR_Slider->value()));

    OM_FL_Slider->setStyleSheet(SLIDER_STYLE);
    OM_BL_Slider->setStyleSheet(SLIDER_STYLE);
    OM_FR_Slider->setStyleSheet(SLIDER_STYLE);
    OM_BR_Slider->setStyleSheet(SLIDER_STYLE);

    /***2.Configuration->PID SpinBox***/
    QGroupBox *PID_GroupBox = new QGroupBox("PID Values");
    QVBoxLayout *vbox_PID = new QVBoxLayout;
    QLabel *kpLabel = new QLabel("Kp:");
    kpSpin = new QDoubleSpinBox();
    kpSpin->setRange(1.0, 200.0);    // plage de valeurs
    kpSpin->setSingleStep(0.5);      // incrément à chaque flèche
    kpSpin->setValue(config->Kp);           // valeur par défaut
    kpSpin->setDecimals(2);          // nombre de décimales affichées
    payload.KP = config->Kp * PID_MULTIPLICATOR;

    QLabel *kiLabel = new QLabel("Ki:");
    kiSpin = new QDoubleSpinBox();
    kiSpin->setRange(0.0, 400.0);    // plage de valeurs
    kiSpin->setSingleStep(0.5);      // incrément à chaque flèche
    kiSpin->setValue(config->Ki);           // valeur par défaut
    kiSpin->setDecimals(2);          // nombre de décimales affichées
    payload.KI = config->Ki * PID_MULTIPLICATOR;

    QLabel *kdLabel = new QLabel("Kd:");
    kdSpin = new QDoubleSpinBox();
    kdSpin->setRange(0.0, 150.0);    // plage de valeurs
    kdSpin->setSingleStep(0.5);      // incrément à chaque flèche
    kdSpin->setValue(config->Kd);           // valeur par défaut
    kdSpin->setDecimals(2);          // nombre de décimales affichées

    payload.KD = config->Kd * PID_MULTIPLICATOR;

    vbox_PID->addWidget(kpLabel);
    vbox_PID->addWidget(kpSpin);
    vbox_PID->addWidget(kiLabel);
    vbox_PID->addWidget(kiSpin);
    vbox_PID->addWidget(kdLabel);
    vbox_PID->addWidget(kdSpin);
    PID_GroupBox->setLayout(vbox_PID);

    /***2.Offset Motors***/
    QGroupBox *offsetsMotorsGroupBox = new QGroupBox("Offsets Motors");
    QGroupBox *offsetsMotorsGroupBoxLeft = new QGroupBox("");
    QGroupBox *offsetsMotorsGroupBoxRight = new QGroupBox("");
    QVBoxLayout *offsetsMotorsVboxLeft = new QVBoxLayout;
    QVBoxLayout *offsetsMotorsVboxRight = new QVBoxLayout;
    QHBoxLayout *offsetsMotorsHbox = new QHBoxLayout;

    offsetsMotorsVboxLeft->addWidget(OM_FL_Label);
    offsetsMotorsVboxLeft->addWidget(OM_FL_Slider);
    offsetsMotorsVboxLeft->addWidget(OM_BL_Label);
    offsetsMotorsVboxLeft->addWidget(OM_BL_Slider);
    offsetsMotorsGroupBoxLeft->setLayout(offsetsMotorsVboxLeft);

    offsetsMotorsVboxRight->addWidget(OM_FR_Label);
    offsetsMotorsVboxRight->addWidget(OM_FR_Slider);
    offsetsMotorsVboxRight->addWidget(OM_BR_Label);
    offsetsMotorsVboxRight->addWidget(OM_BR_Slider);
    offsetsMotorsGroupBoxRight->setLayout(offsetsMotorsVboxRight);

    offsetsMotorsHbox->addWidget(offsetsMotorsGroupBoxLeft);
    offsetsMotorsHbox->addWidget(offsetsMotorsGroupBoxRight);

    offsetsMotorsGroupBox->setLayout(offsetsMotorsHbox);
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

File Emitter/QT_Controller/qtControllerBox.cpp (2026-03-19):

#include <QWidget>
#include <QGroupBox>
#include <QCheckBox>
#include <QVBoxLayout>
#include <QSlider>
#include <QLabel>
#include <QString>
#include <QHBoxLayout>
#include <QShortcut>
#include <QKeyEvent>
#include <QTimer>
#include "qtControllerBox.hpp"
#include "configuration.hpp"

#include "UDP.hpp"
#include "qtStyles.hpp"

#define DSHOT_MIN 48
#define DSHOT_MAX 2047
#define DSHOT_MAX_FAILSAFE 700
#define ANGLE_MAX 1000  // (yaw/pitch/roll)

Controller* local_controller;
QGroupBox *controllerGroupBox = nullptr;
QTimer *timerControllerUpdate = nullptr;
bool KS_enable = false;

bool lastButtonA = false;
bool lastButtonB = false;
bool lastButtonY = false;
bool lastButtonX = false;

void initControllerBox(QWidget* window, Controller* controller){
    local_controller = controller;
    /***2.Security Box***/
    QGroupBox *securityGroupBox = new QGroupBox("Security");
    QCheckBox *FS_Check = new QCheckBox("FailSafe Switch (KeyF, X or Y)");
    QCheckBox *killCheck = new QCheckBox("Kill Switch (KeySpaceBar, A or B)", securityGroupBox);
    killCheck->setStyleSheet(
        "QCheckBox::indicator:checked {"
        "background-color: #aa0000;"
        "border: 1px solid black;"
        "}"
    );
    FS_Check->setChecked(true);
    payload.failSafeSwitch = 1;
    QVBoxLayout *securityVbox = new QVBoxLayout;
    securityVbox->addWidget(FS_Check);
    securityVbox->addWidget(killCheck);
    securityVbox->addStretch(1);
    securityGroupBox->setLayout(securityVbox);

    /***2.Motors Sliders***/
    QGroupBox *motorsGroupBox = new QGroupBox("Motors");
    QVBoxLayout *motorsVbox = new QVBoxLayout;
    QLabel *throttleLabel = new QLabel("");
    QLabel *yawLabel = new QLabel("");
    QLabel *rollLabel = new QLabel("");
    QLabel *pitchLabel = new QLabel("");
    QSlider *throttleSlider = new QSlider(Qt::Horizontal);
    QSlider *yawSlider = new QSlider(Qt::Horizontal);
    QSlider *rollSlider = new QSlider(Qt::Horizontal);
    QSlider *pitchSlider = new QSlider(Qt::Horizontal);

    if (FS_Check->isChecked()){
        throttleSlider->setRange(DSHOT_MIN, DSHOT_MAX_FAILSAFE);
        throttleValue = clampDouble(throttleValue, DSHOT_MIN, DSHOT_MAX_FAILSAFE);
    }else{
        throttleSlider->setRange(DSHOT_MIN, DSHOT_MAX);
    }
    throttleSlider->setValue(DSHOT_MIN);
    throttleSlider->setStyleSheet(SLIDER_STYLE);
    yawSlider->setStyleSheet(SLIDER_STYLE);
    rollSlider->setStyleSheet(SLIDER_STYLE);
    pitchSlider->setStyleSheet(SLIDER_STYLE);
    yawSlider->setRange(-ANGLE_MAX, +ANGLE_MAX);
    yawSlider->setValue(0);
    rollSlider->setRange(-ANGLE_MAX, +ANGLE_MAX);
    rollSlider->setValue(0);
    pitchSlider->setRange(-ANGLE_MAX, +ANGLE_MAX);
    pitchSlider->setValue(0);

    payload.yaw = 0;
    payload.roll = 0;
    payload.pitch = 0;
    payload.throttle = DSHOT_MIN;
    throttleLabel->setText("Throttle : " + QString::number(throttleSlider->value()));
    yawLabel->setText("Yaw : " + QString::number(yawSlider->value()));
    rollLabel->setText("Roll : " + QString::number(rollSlider->value()));
    pitchLabel->setText("Pitch : " + QString::number(pitchSlider->value()));
    motorsVbox->addWidget(throttleLabel);
    motorsVbox->addWidget(throttleSlider);
    motorsVbox->addWidget(pitchLabel);
    motorsVbox->addWidget(pitchSlider);
    motorsVbox->addWidget(rollLabel);
    motorsVbox->addWidget(rollSlider);
    motorsVbox->addWidget(yawLabel);
    motorsVbox->addWidget(yawSlider);
    motorsGroupBox->setLayout(motorsVbox);
    throttleLabel->setStyleSheet(LABEL_CONTROL_STYLE);
    pitchLabel->setStyleSheet(LABEL_CONTROL_STYLE);
    rollLabel->setStyleSheet(LABEL_CONTROL_STYLE);
    yawLabel->setStyleSheet(LABEL_CONTROL_STYLE);

    /**1.Controller**/
    controllerGroupBox = new QGroupBox("Controller");
    controllerGroupBox->setStyleSheet(TITLE_LABEL_STYLE);
    controllerGroupBox->setEnabled(false); // Control non disponible tant que le serial n'est pas activé
    QVBoxLayout *controllerVbox = new QVBoxLayout;

    //motorsGroupBox->setStyleSheet(NORMAL_LABEL_STYLE);
    //securityGroupBox->setStyleSheet(NORMAL_LABEL_STYLE);
    controllerVbox->addWidget(motorsGroupBox);
    controllerVbox->addWidget(securityGroupBox);
    controllerGroupBox->setLayout(controllerVbox);


    QShortcut *FS_Shortcut = new QShortcut(QKeySequence(Qt::Key_F), window);
    QObject::connect(FS_Shortcut, &QShortcut::activated, FS_Check, [FS_Check, throttleSlider]() { //Active/Désactive la limitation moteur (côté drone)
        if (not FS_Check->isChecked()){
            throttleSlider->setRange(DSHOT_MIN, DSHOT_MAX_FAILSAFE);
            throttleValue = clampDouble(throttleValue, DSHOT_MIN, DSHOT_MAX_FAILSAFE);
        }else{
            throttleSlider->setRange(DSHOT_MIN, DSHOT_MAX);
        }
        QSignalBlocker blocker(FS_Check);
        FS_Check->setChecked(not FS_Check->isChecked());
        payload.failSafeSwitch = FS_Check->isChecked(); //Update value for UART

    });
    QObject::connect(FS_Check, &QCheckBox::toggled, FS_Check, [FS_Check, throttleSlider](bool checked) {
        // Cette lambda est appelée à chaque clic sur la checkbox
        if (checked){
            throttleSlider->setRange(DSHOT_MIN, DSHOT_MAX_FAILSAFE);
            throttleValue = clampDouble(throttleValue, DSHOT_MIN, DSHOT_MAX_FAILSAFE);
        }else{
            throttleSlider->setRange(DSHOT_MIN, DSHOT_MAX);
        }

        QSignalBlocker blocker(FS_Check);
        payload.failSafeSwitch = checked;
    });


    QShortcut *killShortcut = new QShortcut(QKeySequence(Qt::Key_Space), window);
    QObject::connect(killShortcut,
                     &QShortcut::activated,
                     killCheck,
                     [killCheck]() {
                         if (KS_enable){
                             QSignalBlocker blocker(killCheck);
                             killCheck->setChecked(true);
                             killCheck->setEnabled(false);
                             payload.killSwitch = 1;
                         }
                     });

    QObject::connect(killCheck, &QCheckBox::toggled, killCheck, [killCheck](bool checked){ // Désactive l'option KS une fois activée
        checked=checked; // no effect, avoid warning
        QSignalBlocker blocker(killCheck);
        killCheck->setEnabled(false);
        payload.killSwitch = 1;
        std::cout << "KILLSWITCHED" << std::endl;
    });

    QObject::connect(throttleSlider, &QSlider::valueChanged, [throttleLabel](int value){ //Update la valeur de Throttle
        throttleLabel->setText("Throttle : " + QString::number(value));
        payload.throttle = value;  //Update value for UART
    });

    QObject::connect(yawSlider, &QSlider::valueChanged, [yawLabel](int value){ //Update la valeur de Throttle
        yawLabel->setText("Yaw : " + QString::number(value));
        payload.yaw = value;  //Update value for UART
    });
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

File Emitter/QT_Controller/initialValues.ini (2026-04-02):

[OFFSET]
offsetMotorBL=12
offsetMotorBR=0
offsetMotorFL=26
offsetMotorFR=0

[PID]
Kd=3
Ki=50
Kp=80

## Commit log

2025-10-16 Hard iron magnetometer correction
    [imu.c]
2025-10-23 PWM motors simu v1
2025-11-09 Portage FrameWork ESP IDF to Arduino
2025-11-10 Ajout script arduino pour telecommande
2025-11-10 Correction via yaw roll pitch fonctionnel
    [main.cpp]
2025-11-16 Kicad drone PCB
    [DronePCB-B_Cu.gbl, DronePCB-B_Mask.gbs, DronePCB-B_Paste.gbp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]
2025-12-03 Added Kicad for drone Remote Controller
    [Manette drone Robotech.kicad_pcb, Manette drone Robotech.kicad_sch]
2025-12-04 PCB Drone et manette finis avec gerbers générés
    [DronePCB-B_Cu.gbl, DronePCB-B_Mask.gbs, DronePCB-B_Paste.gbp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]
2025-12-04 mise a jour de tous les fichiers git
    [Manette drone Robotech.kicad_pcb, Manette drone Robotech.kicad_sch]
2025-12-05 Fix conversion issue on payload
    [main.ino]
2025-12-05 pid file
2025-12-05 KillSwitch delta radio a 5000 pour tester les reactions moteurs
2025-12-06 Correction Drone pinout et génération gerber
    [DronePCB-B_Cu.gbl, DronePCB-B_Mask.gbs, DronePCB-B_Paste.gbp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]
2025-12-10 gerbers et code fonctionnel cut a 45°
    [DronePCB-B_Cu.gbl, DronePCB-B_Mask.gbs, DronePCB-B_Paste.gbp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]
2026-01-10 Code recoit infos manette, gere le throttle, et gestion du killswitch OK. Cependant, PB de GPIO qui se détruisent, probablement pic de courant ou tension
2026-02-07 PID Kd and motors offsets added
2026-02-09 PID security update with I begin value
2026-02-11 Communication by UDP to avoid NRF24L01 bugs
    [UDP.cpp, UDP.hpp, UDP_reception.cpp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]
2026-02-14 Sauvegarde des offsets moteurs QT Interface
2026-02-14 Changement pas du PID slider QT interface
2026-02-15 Ajout Drone Box for battery data
2026-02-16 QT Interface for battery
2026-02-16 fix battery pin
2026-02-25 PCB avec nouveau connecteur JST SH + buffer
    [DronePCB-B_Cu.gbl, DronePCB-B_Mask.gbs, DronePCB-B_Paste.gbp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]
2026-02-25 Critique : Inclusion de ROLL et PITCH dans le drone, code QT pour roll pitch egalement
2026-02-25 Drone code fix (see last commit)
    [UDP_reception.cpp, imu.cpp]
2026-03-01 Qqs corrections et stylessheets
    [qtBoxConfiguration.cpp, qtControllerBox.cpp, qtDroneBox.cpp]
2026-03-01 Throttle par dérivée et non pas valeur brute
2026-03-12 CRITICAL FIX! Cause : function with no return | Consequences : Illegal instruction/ESP reboot
    [imu.cpp]
2026-03-12 Debug WIP motors telemetry
2026-03-12 Inversion axis +pitch and -pitch & Inversion axis roll+ and roll- in QT controller. Delete some ESP debugs displays and limit failsafe value to 800
    [UDP.cpp, UDP_reception.cpp, main.ino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]
2026-03-13 Yaw integration in drone code | Non-tested feature
2026-03-13 QT Wifi connection UI UX update | Try to debug KS issue
    [UDP.cpp, main.ino]
2026-03-13 Communication Bug fixed by use of threads for network manager QT calls
    [UDP.cpp]
2026-03-17 Add PID edit by controller + UI WIP
2026-03-18 Rework throttle curve in QT
    [UDP.cpp, initialValues.ini, qtControllerBox.cpp]
2026-03-19 yaw on throttle joystick + font resize
2026-04-02 yaw inverted issue
2026-04-02 offsets accelerometer fix
